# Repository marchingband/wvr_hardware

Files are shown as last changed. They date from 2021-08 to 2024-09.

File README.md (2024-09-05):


# wvr_hardware

Find the Kicad files in their respective folders, more will be added with time.  
We have done our best to make these files portable, using project specific libraries.  
These are for Kicad V5.

In the JLC_PCB folder you can find all the files needed to order WVR BASIC from JLC with assembly. Kindly donated by Robin of Atonal Circuits.

There are 3 branches. v2.1 is the newest one, which includes a footprint for the XIAO SAMD21 on the back side, and a resistor on the front side to connect the UARTS.
click "main" above, and select v2.1 to move to this new branch
  
# pinouts

<pre>
pinout for WVR :

WVR PIN | MAKERS BOARD PIN | ESP32 GPIO | NOTES  
  
D0      |       14         |    3       | FTDI RX  
D1      |       13         |    1       | FTDI TX  
D2      |       12         |    21      | USB MIDI In (when using USB backpack firmware)  
D3      |       11         |    19      |  
D4      |       10         |    18      |  
D5      |       9          |    5       |  
D6      |       8          |    0       | no ADC when WIFI active, strapping pin for bootloader mode (must be high or floating at boot)  
D7      |       7          |    36      | no built-in pullups, input only  
D8      |       6          |    39      | no built-in pullups, input only  
D9      |       5          |    34      | no built-in pullups, input only  
D10     |       4          |    35      | no built-in pullups, input only  
D11     |       3          |    32      |  
D12     |       2          |    33      |  
D13     |       1          |    27      | no ADC when WIFI active  
</pre>  
  
# wiring diagram
Example of powering with the 5v pin, instead of the USB jack, with breadboard-compatible push button and headphone jack attached.  
When WVR's WiFi is active, current consumption can peak significantly, as the radio consumes a fair bit of current. We recommend a PSU that provides 500mA or more at 5v. Any voltage between 5vDC and 9vDC will work, but keep in mind that higher voltage will result in more heat produced by the voltage regulator, which can get very hot! If you experience brown-outs during the boot sequence, try a PSU with a higher current rating.  

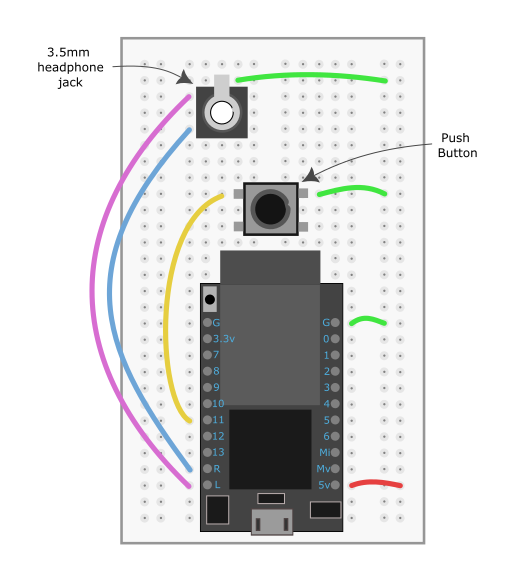
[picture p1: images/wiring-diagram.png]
wvr wiring diagram


# wiring diagram for midi control
Example of controlling WVR from a RPi Pico using MIDI. Note that because MIDI is optically isolated, both boards can be powered independantly, by USB, or otherwise. Thus there are no power rails connected in this diagram. It is also OK to power both boards from the same power source, it is just not necissary to do so.  
Note also, the MIDI signal does not use a ground connection. MIDI is a 2-line protocol, just +5v and TX are needed.  
Here is a great Arduino library to generate MIDI signals from the RPi Pico, or most any other microcontroller: https://github.com/FortySevenEffects/arduino_midi_library

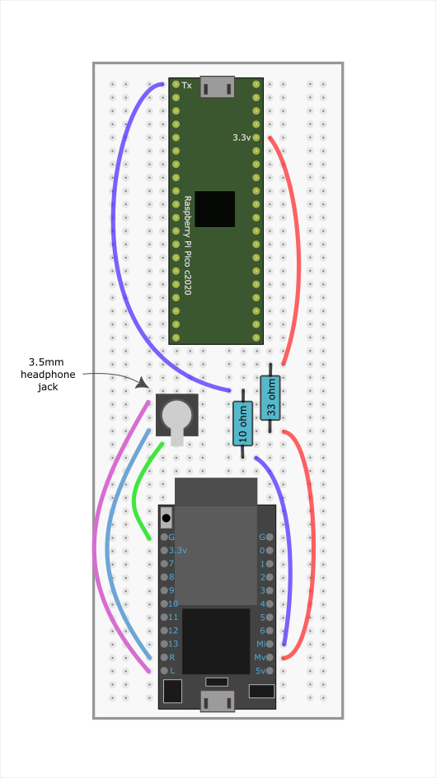
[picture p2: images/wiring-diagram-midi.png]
wvr wiring diagram


This code snippet for the PiPico sends some basic MIDI messages and flashes the onboard LED.
```
#include <Arduino.h>
#include <MIDI.h>

using Transport = MIDI_NAMESPACE::SerialMIDI<HardwareSerial>;
Transport serialMIDI(Serial1);
MIDI_NAMESPACE::MidiInterface<Transport> MIDI((Transport&)serialMIDI);

void setup()
{
  pinMode(LED_BUILTIN, OUTPUT);
  MIDI.begin(MIDI_CHANNEL_OMNI); // Launch MIDI
}

void loop()
{
    MIDI.sendNoteOn(40, 127, 1);    // Send a Note (pitch 40, velocity 127 on channel 1)
    digitalWrite(LED_BUILTIN, HIGH);
    delay(1000);                    // Wait for a second
    MIDI.sendNoteOff(40, 0, 1);     // Stop the note
    digitalWrite(LED_BUILTIN, LOW);
    delay(1000);
}
```

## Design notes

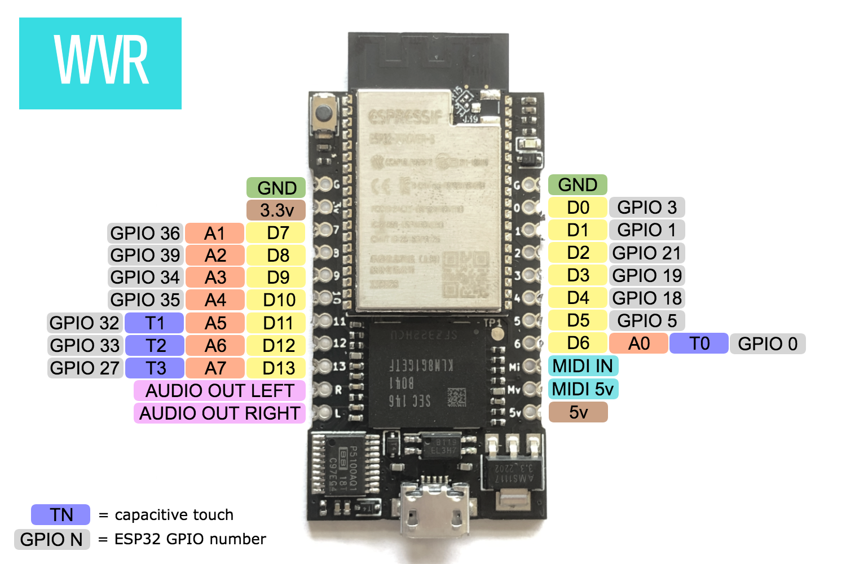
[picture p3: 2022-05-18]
images/wvr_pinout.png

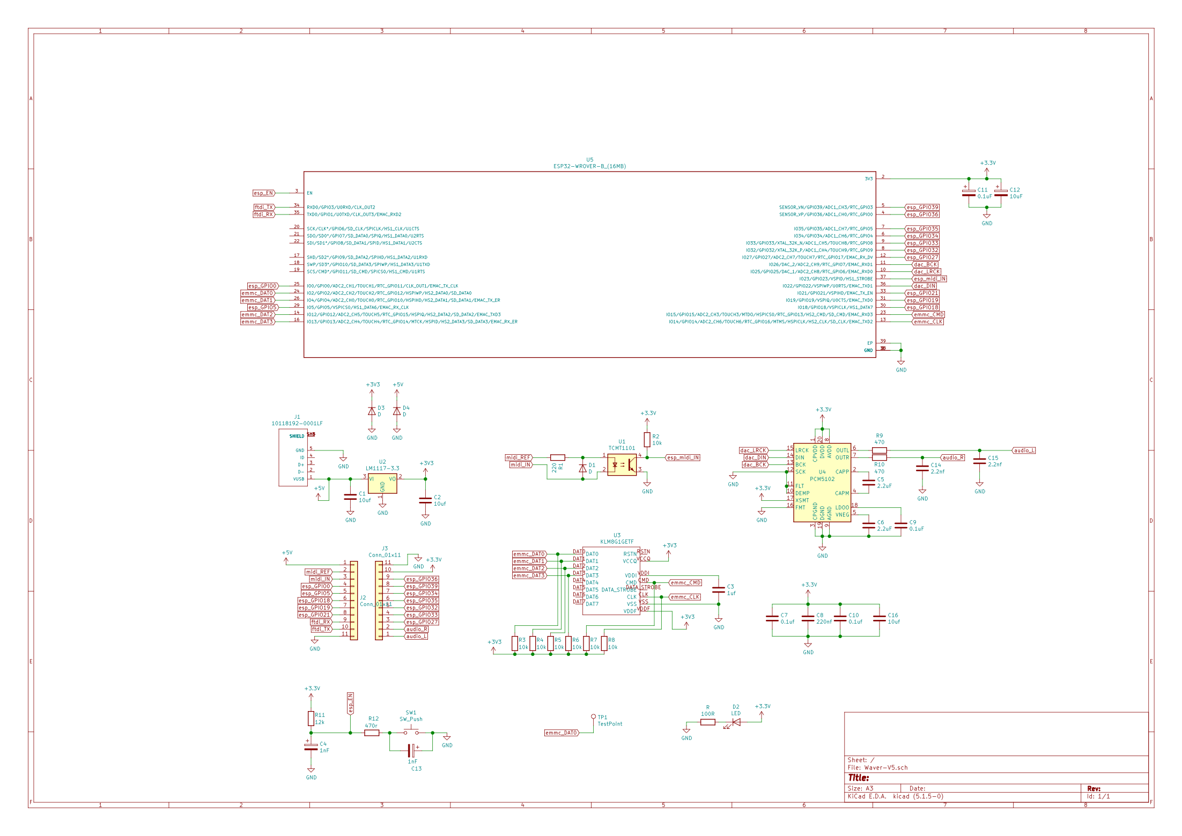
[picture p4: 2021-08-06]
wvr_v.1.0/schematic.png

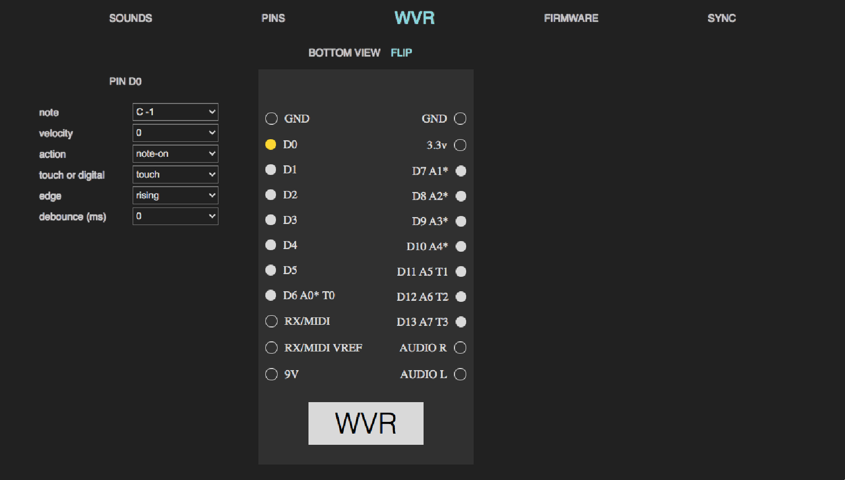
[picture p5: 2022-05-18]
images/gui_pins.png

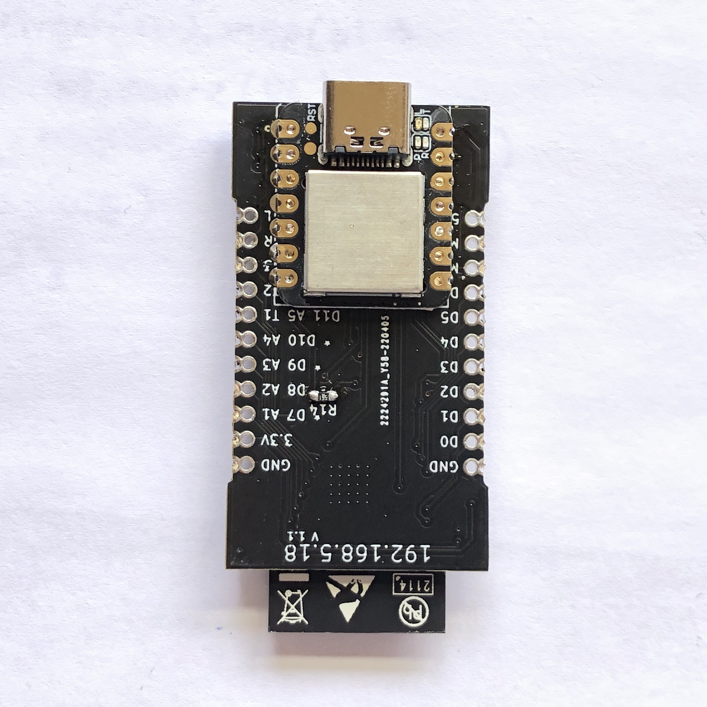
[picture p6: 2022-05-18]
images/backack.jpeg

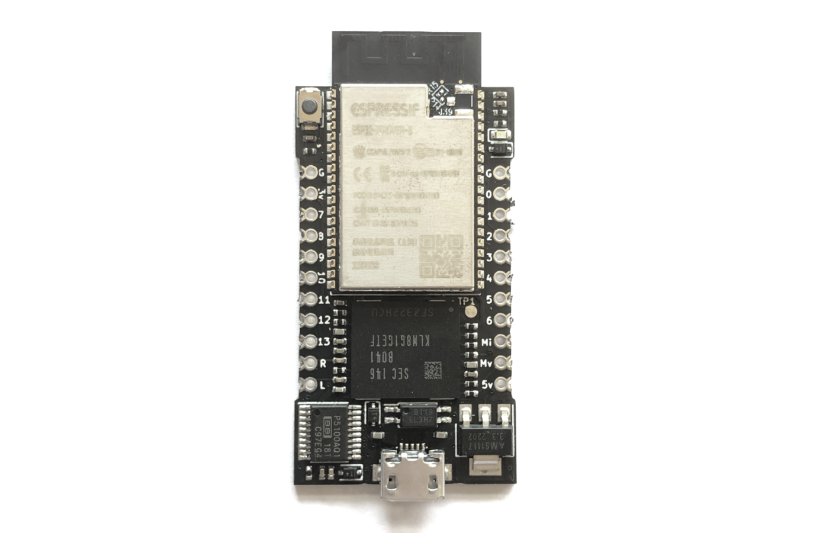
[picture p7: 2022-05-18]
images/wvr.png

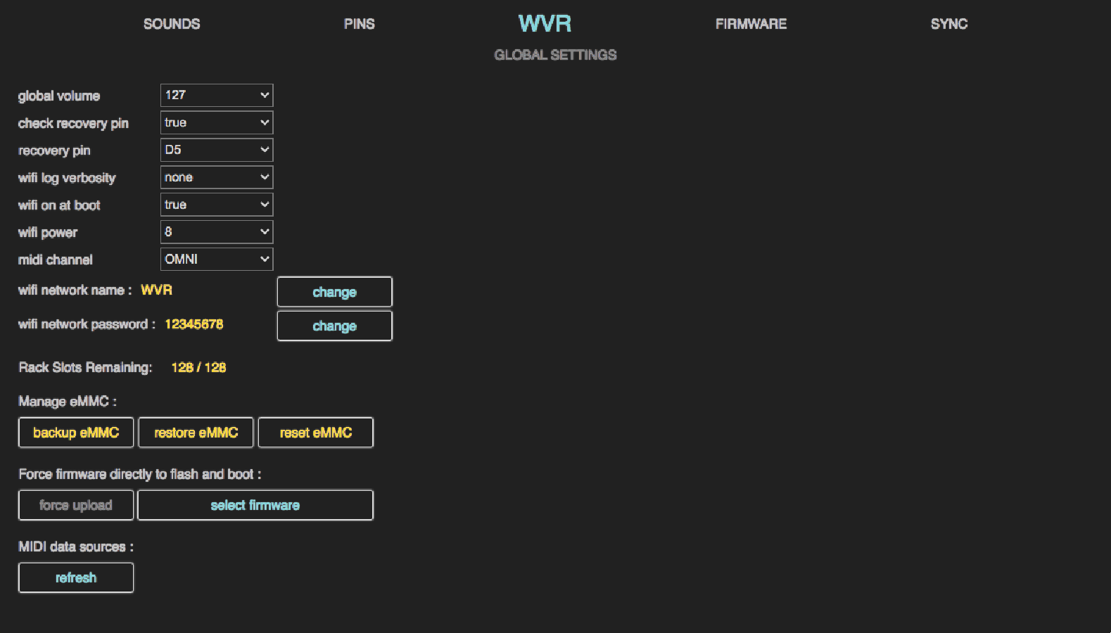
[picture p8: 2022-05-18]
images/gui_global.png

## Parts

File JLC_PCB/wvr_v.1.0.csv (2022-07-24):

Comment | Designator | Footprint | LCSC
10uf | C1,C2,C16 | Capacitor_SMD:C_0402_1005Metric | C15525
0.1uf | C7,C10 | Capacitor_SMD:C_0402_1005Metric | C1525
10uF | C12 | Capacitor_SMD:C_0402_1005Metric | C15525
2.2nf | C14,C15 | Capacitor_SMD:C_0402_1005Metric | C1531
1uf | C3 | Capacitor_SMD:C_0402_1005Metric | C52923
1nF | C4,C13 | Capacitor_SMD:C_0402_1005Metric | C1523
2.2uF | C5,C6 | Capacitor_SMD:C_0402_1005Metric | C12530
220nf | C8 | Capacitor_SMD:C_0402_1005Metric | C16772
0.1uF | C9,C11 | Capacitor_SMD:C_0402_1005Metric | C1525
D | D1,D3,D4 | Diode_SMD:D_SOD-323 | C2128
LED | D2 | LED_SMD:LED_0603_1608Metric | C72041
10118192-0001LF | J1 | Waver:USB-MICRO-B_C40942 | C132564
Conn_01x11 | J2 | Waver:CAST_HEADER_11_LEFT_2
Conn_01x11 | J3 | Waver:CAST_HEADER_11_RIGHT_2
220 | R1 | Resistor_SMD:R_0402_1005Metric | C25091
12k | R11 | Resistor_SMD:R_0402_1005Metric | C25752
470r | R12,R13 | Resistor_SMD:R_0402_1005Metric | C25117
280 | R2 | Resistor_SMD:R_0402_1005Metric | C423200
10k | R3,R4,R5,R6,R7,R8 | Resistor_SMD:R_0402_1005Metric | C25744
470 | R9,R10 | Resistor_SMD:R_0402_1005Metric | C25117
SW_Push | SW1 | Button_Switch_SMD:SW_Push_SPST_NO_Alps_SKRK | C720477
TestPoint | TP1 | TestPoint:TestPoint_Pad_D1.5mm
EL3H7 | U1 | Package_SO:SOP-4_4.4x2.6mm_P1.27mm | C32565
LM1117-3.3 | U2 | Package_TO_SOT_SMD:SOT-223-3_TabPin2 | C23984
KLM8G1GETF | U3 | Waver:KLM8G1GETF_ALL_PADS | C499918
PCM5100 | U4 | Package_SO:TSSOP-20_4.4x6.5mm_P0.65mm | C1540069
ESP32-WROVER-B_(16MB) | U5 | Waver:XCVR_ESP32-WROVER-B_(16MB) | C529591

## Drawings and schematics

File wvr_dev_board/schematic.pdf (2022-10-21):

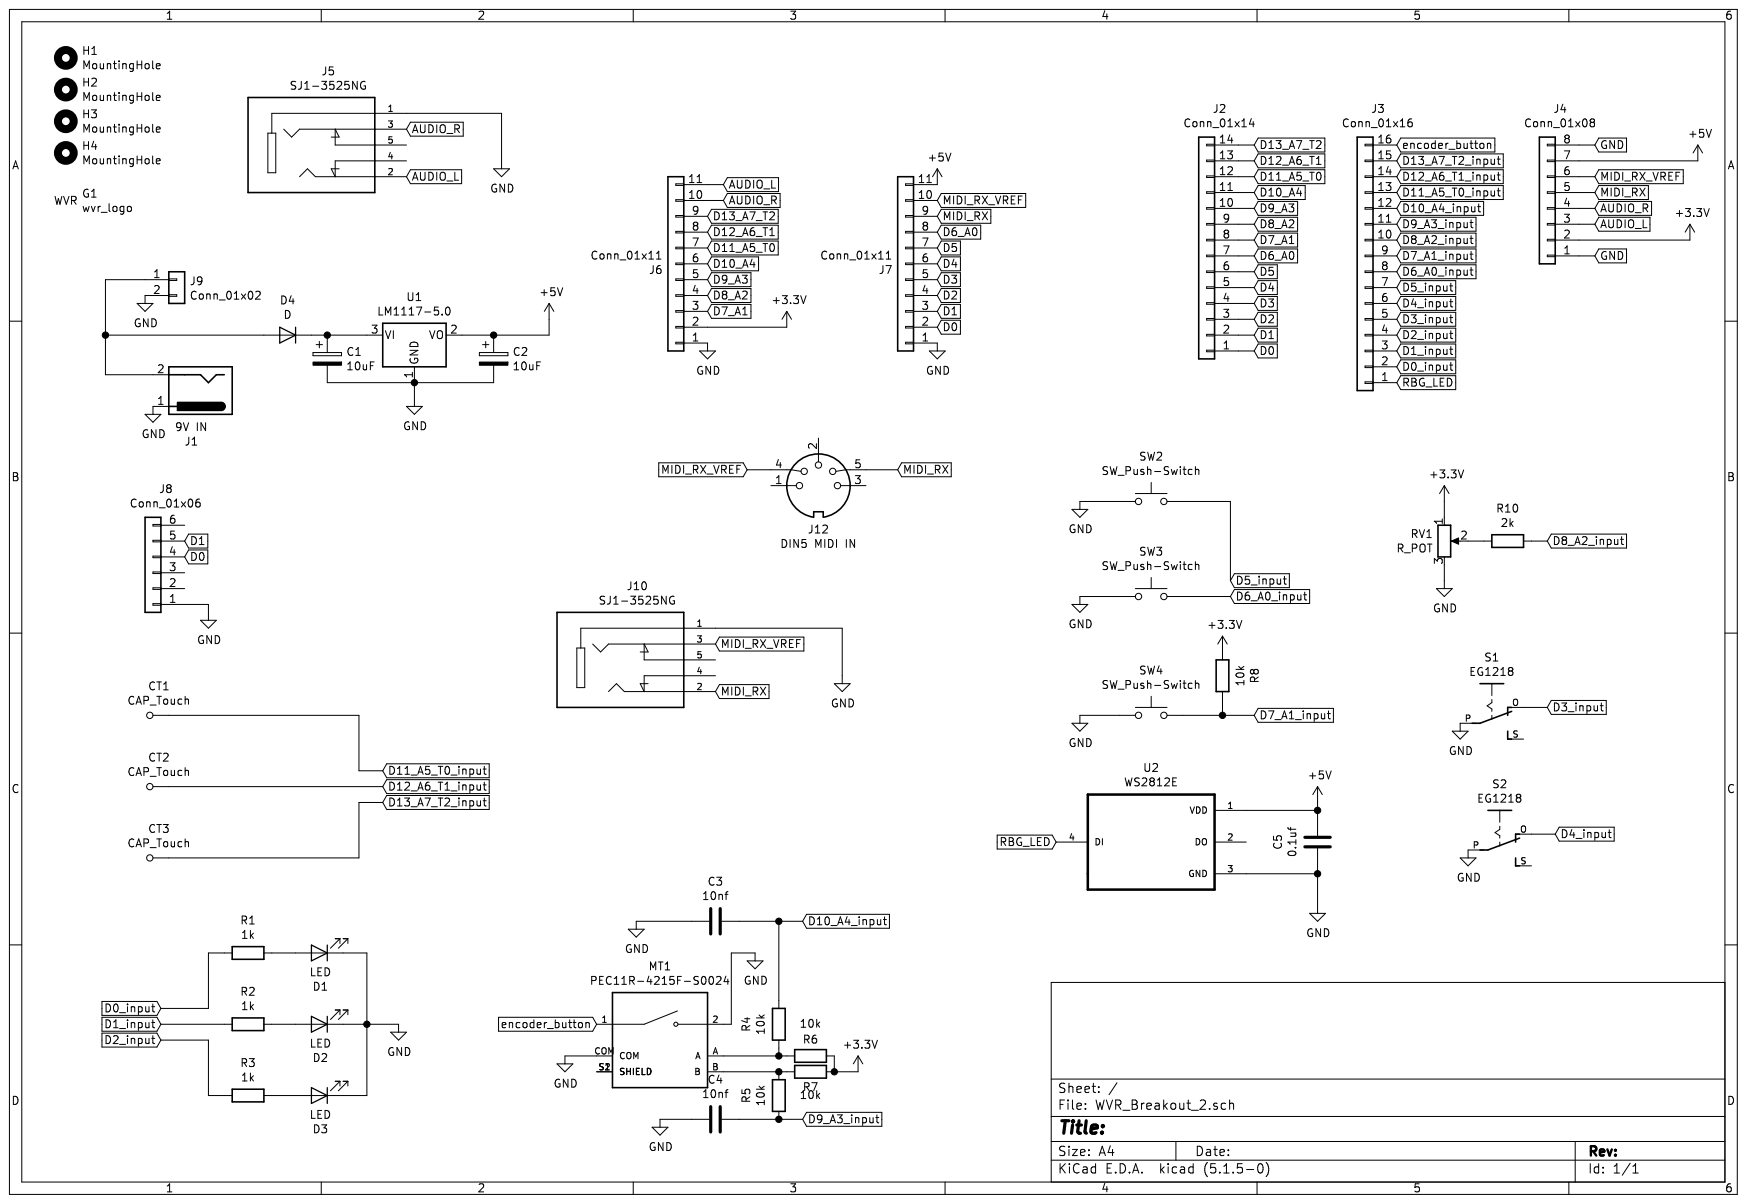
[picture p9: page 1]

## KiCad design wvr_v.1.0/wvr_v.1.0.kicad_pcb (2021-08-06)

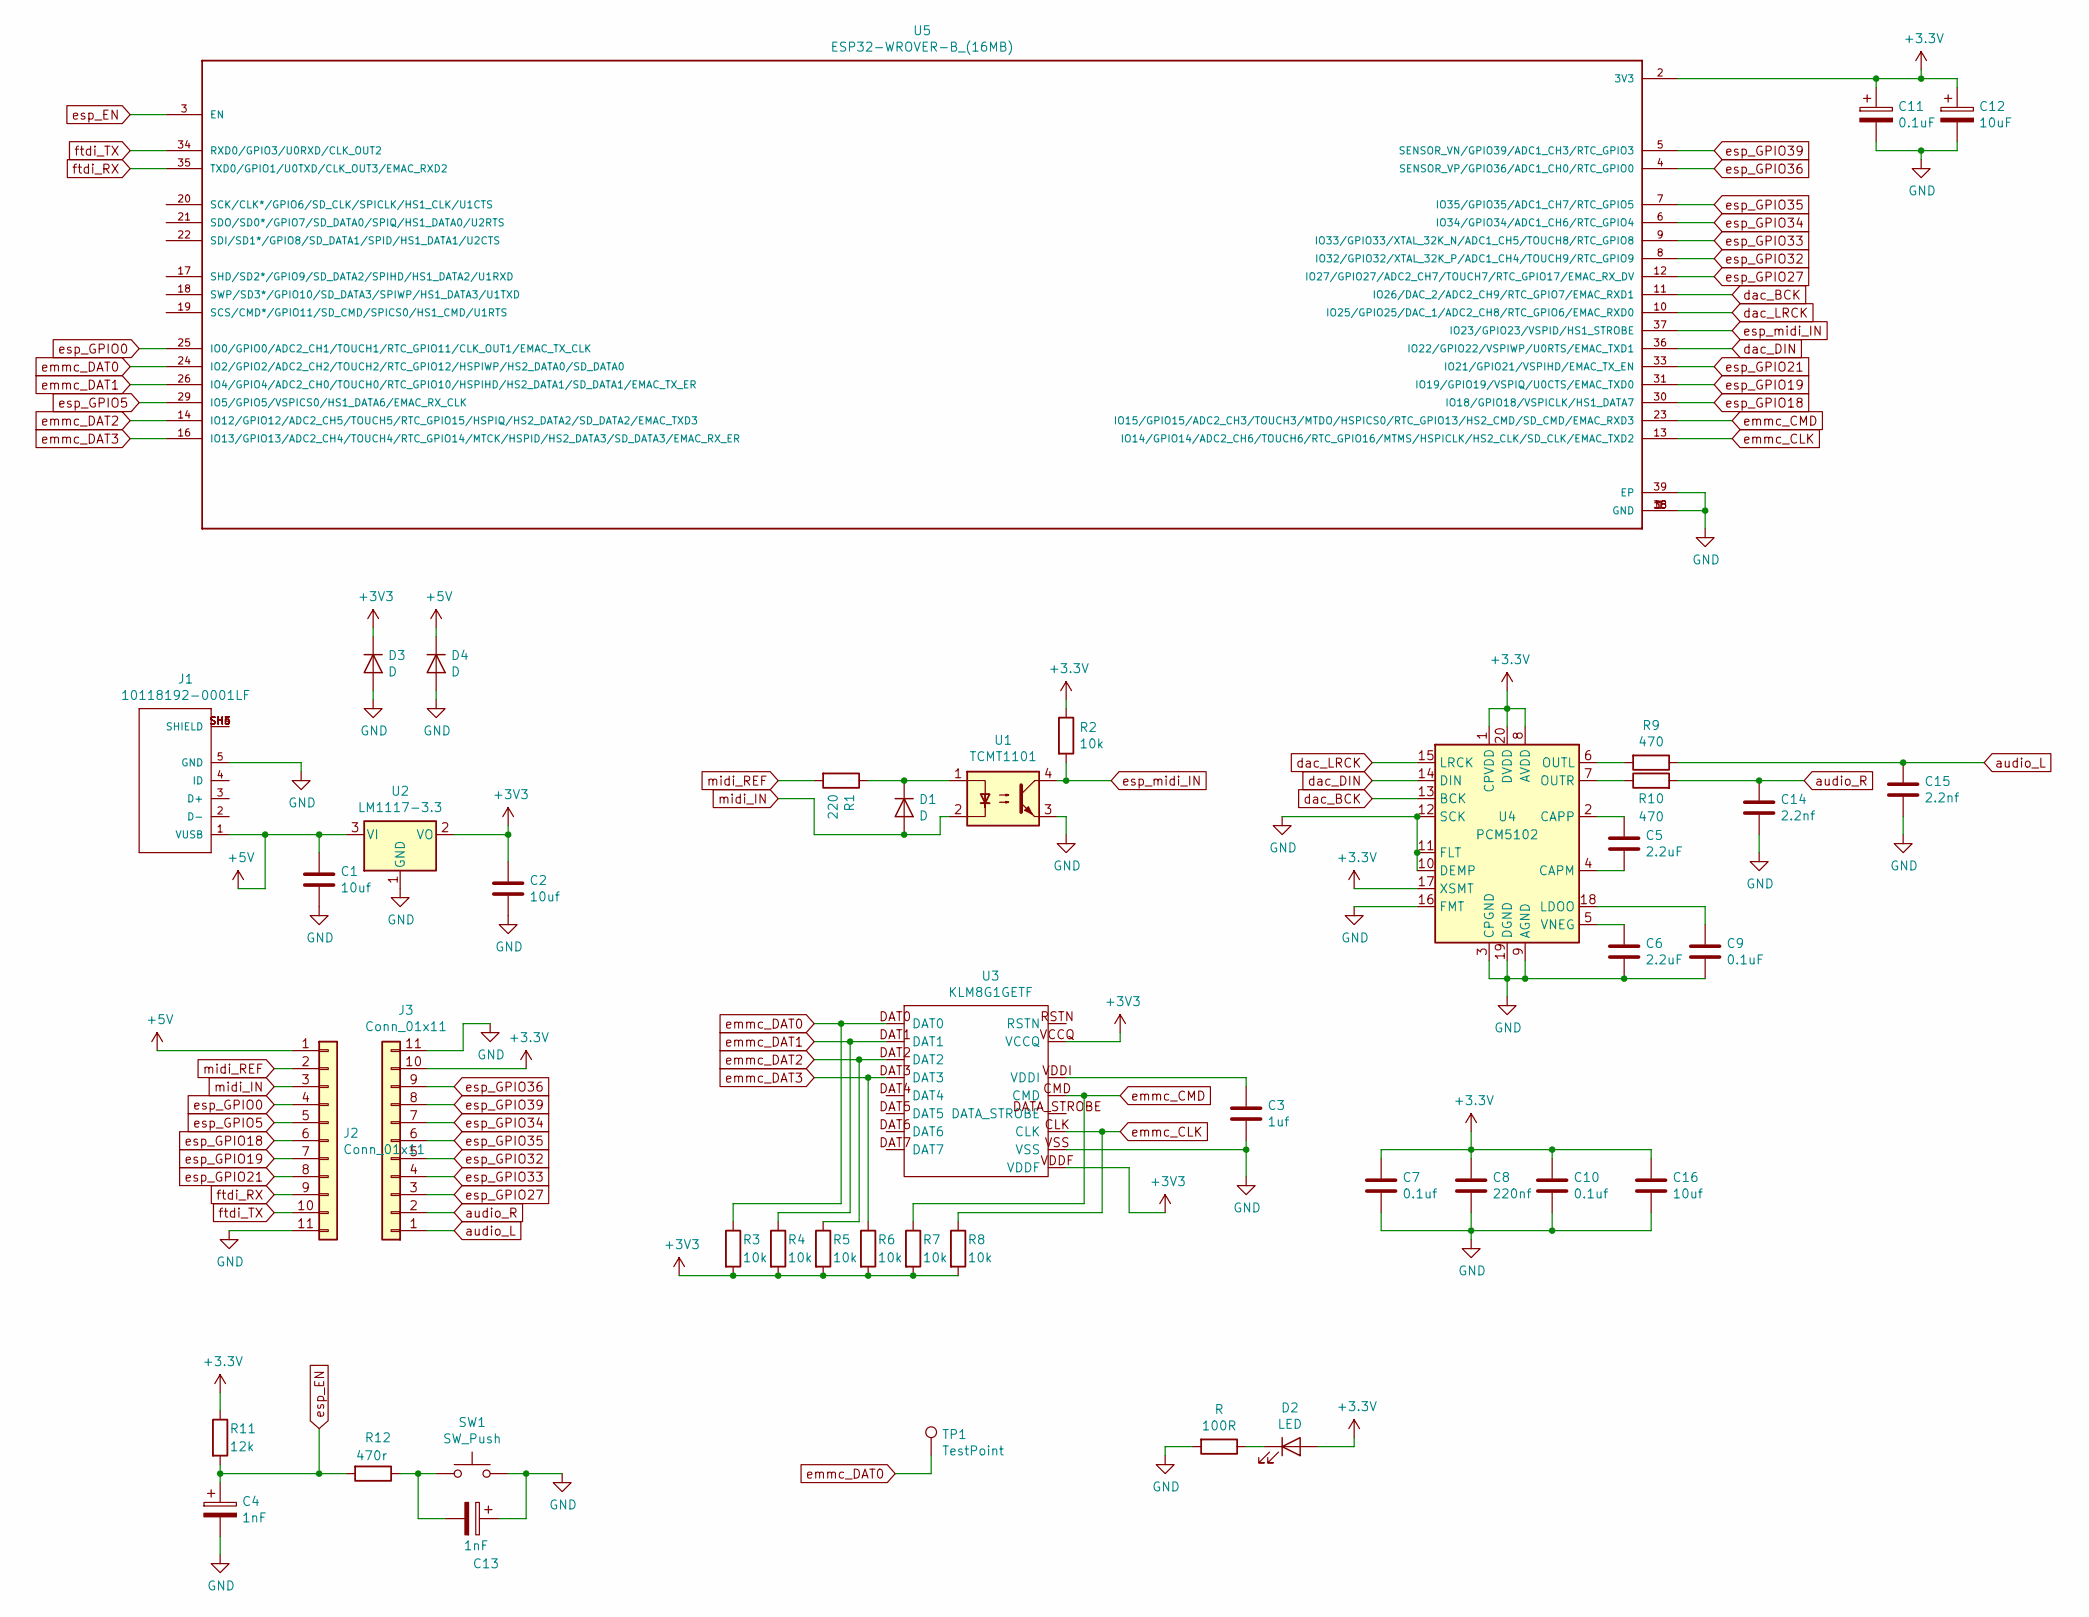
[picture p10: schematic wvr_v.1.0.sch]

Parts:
C1, C2, C16: 10uf; C_0402_1005Metric
C3: 1uf; C_0402_1005Metric
C4, C13: 1nF; C_0402_1005Metric
C5, C6: 2.2uF; C_0402_1005Metric
C7, C10: 0.1uf; C_0402_1005Metric
C8: 220nf; C_0402_1005Metric
C9, C11: 0.1uF; C_0402_1005Metric
C12: 10uF; C_0402_1005Metric
C14, C15: 2.2nf; C_0402_1005Metric
D1, D3, D4: D; D_SOD-323
D2: LED; LED_0603_1608Metric
J1: 10118192-0001LF; USB-MICRO-B_C40942
J2: Conn_01x11; CAST_HEADER_11_LEFT_2
J3: Conn_01x11; CAST_HEADER_11_RIGHT_2
R: 100R; R_0402_1005Metric
R1: 220; R_0402_1005Metric
R2, R3, R4, R5, R6, R7, R8: 10k; R_0402_1005Metric
R9, R10: 470; R_0402_1005Metric
R11: 12k; R_0402_1005Metric
R12: 470r; R_0402_1005Metric
SW1: SW_Push; SW_Push_SPST_NO_Alps_SKRK
TP1: TestPoint; TestPoint_Pad_D1.5mm
U1: TCMT1101; SOP-4_4.4x2.6mm_P1.27mm
U2: LM1117-3.3; SOT-223-3_TabPin2; LCSC C23984
U3: KLM8G1GETF; KLM8G1GETF_ALL_PADS; LCSC C499918
U4: PCM5102; TSSOP-20_4.4x6.5mm_P0.65mm; LCSC C131154
U5: ESP32-WROVER-B_(16MB); XCVR_ESP32-WROVER-B_(16MB); LCSC C529591

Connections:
+5V: C1.1, D4.1 (K), J1.1 (VUSB), J2.1, U2.3 (VI)
GND: C1.2, C2.2, C3.2, C4.2, C6.2, C7.2, C8.2, C9.2, C10.2, C11.2, C12.2, C13.1, C14.2, C15.2, C16.2, D3.2 (A), D4.2 (A), J1.5 (GND), J2.11, J3.11, R.2, SW1.2, U1.3, U2.1 (GND), U3.VSS, U4.3 (CPGND), U4.9 (AGND), U4.10 (DEMP), U4.11 (FLT), U4.12 (SCK), U4.16 (FMT), U4.19 (DGND), U5.1 (GND), U5.15 (GND), U5.38 (GND), U5.39 (EP); also elsewhere on the board
unnamed: C3.1, U3.VDDI
unnamed: C5.1, U4.2 (CAPP)
unnamed: C5.2, U4.4 (CAPM)
unnamed: C6.1, U4.5 (VNEG)
unnamed: C9.1, U4.18 (LDOO)
unnamed: C13.2, R12.1, SW1.1
unnamed: D1.1 (K), R1.1, U1.1
unnamed 9: D2.1 (K), R.1; also elsewhere on the board
unnamed: J1.SH3 (SHIELD), J1.SH4 (SHIELD), J1.SH5 (SHIELD), J1.SH6 (SHIELD)
unnamed: R9.2, U4.6 (OUTL)
unnamed: R10.1, U4.7 (OUTR)
audio_L: C15.1, J3.1, R9.1
audio_R: C14.1, J3.2, R10.2
dac_BCK: U4.13 (BCK), U5.11 (IO26/DAC_2/ADC2_CH9/RTC_GPIO7/EMAC_RXD1)
dac_DIN: U4.14 (DIN), U5.36 (IO22/GPIO22/VSPIWP/U0RTS/EMAC_TXD1)
dac_LRCK: U4.15 (LRCK), U5.10 (IO25/GPIO25/DAC_1/ADC2_CH8/RTC_GPIO6/EM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)
emmc_CLK: R8.1, U3.CLK, U5.13 (IO14/GPIO14/ADC2_CH6/TOUCH6/RTC_GPIO16/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)
emmc_CMD: R7.1, U3.CMD, U5.23 (IO15/GPIO15/ADC2_CH3/TOUCH3/MTDO/HSPICS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)
emmc_DAT0: R3.1, TP1.1, U3.DAT0, U5.24 (IO2/GPIO2/ADC2_CH2/TOUCH2/RTC_GPIO12/HS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); also elsewhere on the board
emmc_DAT1: R4.1, U3.DAT1, U5.26 (IO4/GPIO4/ADC2_CH0/TOUCH0/RTC_GPIO10/HS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)
emmc_DAT2: R5.1, U3.DAT2, U5.14 (IO12/GPIO12/ADC2_CH5/TOUCH5/RTC_GPIO15/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)
emmc_DAT3: R6.1, U3.DAT3, U5.16 (IO13/GPIO13/ADC2_CH4/TOUCH4/RTC_GPIO14/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)
esp_EN: C4.1, R11.2, R12.2, U5.3 (EN)
esp_GPIO0: J2.4, U5.25 (IO0/GPIO0/ADC2_CH1/TOUCH1/RTC_GPIO11/CL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)
esp_GPIO5: J2.5, U5.29 (IO5/GPIO5/VSPICS0/HS1_DATA6/EMAC_RX_CLK)
esp_GPIO18: J2.6, U5.30 (IO18/GPIO18/VSPICLK/HS1_DATA7)
esp_GPIO19: J2.7, U5.31 (IO19/GPIO19/VSPIQ/U0CTS/EMAC_TXD0)
esp_GPIO21: J2.8, U5.33 (IO21/GPIO21/VSPIHD/EMAC_TX_EN)
esp_GPIO27: J3.3, U5.12 (IO27/GPIO27/ADC2_CH7/TOUCH7/RTC_GPIO17/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)
esp_GPIO32: J3.5, U5.8 (IO32/GPIO32/XTAL_32K_P/ADC1_CH4/TOUCH9/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)
esp_GPIO33: J3.4, U5.9 (IO33/GPIO33/XTAL_32K_N/ADC1_CH5/TOUCH8/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)
esp_GPIO34: J3.7, U5.6 (IO34/GPIO34/ADC1_CH6/RTC_GPIO4)
esp_GPIO35: J3.6, U5.7 (IO35/GPIO35/ADC1_CH7/RTC_GPIO5)
esp_GPIO36: J3.9, U5.4 (SENSOR_VP/GPIO36/ADC1_CH0/RTC_GPIO0)
esp_GPIO39: J3.8, U5.5 (SENSOR_VN/GPIO39/ADC1_CH3/RTC_GPIO3)
esp_midi_IN: R2.2, U1.4, U5.37 (IO23/GPIO23/VSPID/HS1_STROBE)
ftdi_RX: J2.9, U5.35 (TXD0/GPIO1/U0TXD/CLK_OUT3/EMAC_RXD2)
ftdi_TX: J2.10, U5.34 (RXD0/GPIO3/U0RXD/CLK_OUT2)
midi_IN: D1.2 (A), J2.3, U1.2
midi_REF: J2.2, R1.2

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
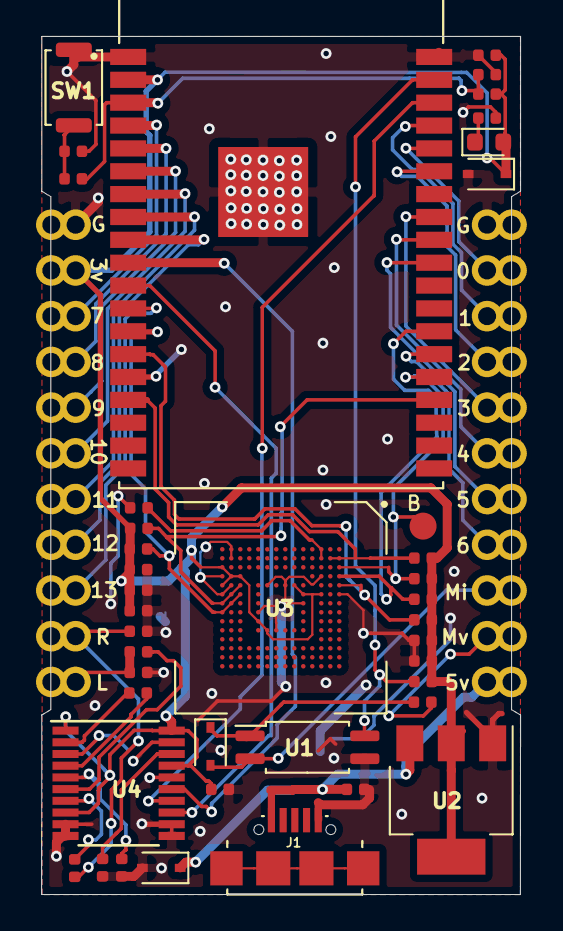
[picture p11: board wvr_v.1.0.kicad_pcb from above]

Board: 2 copper layers, 26.6 x 47.7 mm, 43 parts (0 on the bottom side), 43 nets.

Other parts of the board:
B: TestPoint; TestPoint_Pad_D1.5mm
R13: 22; R_0402_1005Metric

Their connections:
GND: R13.2; also elsewhere on the board
unnamed 9: R13.1; also elsewhere on the board
emmc_DAT0: B.1; also elsewhere on the board

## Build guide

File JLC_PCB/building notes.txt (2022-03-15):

The build at JLCPCB is successful using SURFACE FINISH = ENIG-RoHS.
(this is more pricey but this ensure U3: eMMC to be soldered correctly).

Here are the parameters I used:
Base Material: FR-4
Layers: 2
PCB Thickness: 1.6
Surface Finish: ENIG-RoHS
Deburring/Edge rounding: No
Outer Copper Weight: 1
Gold Fingers: No
Flying Probe Test: Fully Test
Castellated Holes: no
Remove Order Number: No
Material Type: FR4-Standard Tg 130-140C

GERBER = WVR_GERBER.zip
BOM = wvr_v.1.0.csv
CPL (placement) = wvr_v.1.0-top-pos.csv

During SMT order process, parts placement review may show at a wrong scale (it’s a bug from JLC).
Part orientations are all correct.

GOOD LUCK!

Robin 

March 2022 - atonalcircuits@gmail.com

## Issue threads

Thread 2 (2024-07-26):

platformio.ini error

patricecolet, 2024-07-26:
I've been having multiple definitions errors with platform.ini file provided in README.md

For fixing it just remove dependencies like this:
```

; PlatformIO Project Configuration File
;
;   Build options: build flags, source filter
;   Upload options: custom upload port, speed and extra flags
;   Library options: dependencies, extra library storages
;   Advanced options: extra scripting
;
; Please visit documentation for the other options and examples
; https://docs.platformio.org/page/projectconf.html

[env:esp-wrover-kit]
platform = espressif32@6.2.0
framework = arduino
board = esp-wrover-kit
lib_deps =
    https://github.com/marchingband/wvr.git
# those dependencies are already declared in git, so it induces multiple definition errors
#    https://github.com/philbowles/ESPAsyncWebServer.git
#    https://github.com/philbowles/AsyncTCP.git
build_flags = -DBOARD_HAS_PSRAM -mfix-esp32-psram-cache-issue
monitor_speed = 115200
# upload_port = /dev/cu.usbserial-A50285BI

```

This is explained [here](https://community.platformio.org/t/libraries-showing-twice-in-pio-libdeps/22870/7).

marchingband, 2024-07-26:
Thank you so much!
I had this error come up with another project last week, I am suspicious that something may have changed in PIO that triggered it. I have updated the README to reflect your changes.

marchingband, 2024-07-26:
fixed

Closed 2024-07-26.

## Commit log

2021-08-06 update schematic resistor values
    [wvr_v.1.0.sch]
2022-03-15 add JLC
    [wvr_v.1.0.csv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]
2022-10-21 add dev board schematic pdf
2023-04-13 add wiring diagram
2023-05-18 add midi wiring diagram
2024-09-05 Add files via upload
    Update midi wiring diagram

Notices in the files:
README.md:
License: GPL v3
